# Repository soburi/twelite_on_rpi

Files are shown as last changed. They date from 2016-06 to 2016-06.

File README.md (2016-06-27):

TWE-Lite on RPi
===============

What is this?
-------------
TWE-LiteをRaspberry PiのUARTに直接接続するボードです。
ラズパイのケースにそのまま収まったり、TWE-LiteRのアダプタをケチれたりするので、
Border-Routerを作るときに役に立つはずのものです。

How to use it?
--------------
[私家版jenprog](https://github.com/soburi/jenprog)
[(https://github.com/soburi/jenprog)](https://github.com/soburi/jenprog)
で書き込みができるようになっています。

* TX     - RX
* RX     - TX
* GPIO9  - SPIMISO(Programming-mode)
* GPIO23 - reset

でTWE-LiteとRaspberryPiを接続しています。

```
jenprog -c serial -t /dev/ttyS0 --rpi --spimiso-pin=9 \
--reset-pin=23 --verbose -p slip-radio.jn516x.bin
```

のようにすると、イメージの焼き込みができます。
シリアルの指定はRPi3の場合は/dev/ttyS0、RPi2/1は/dev/ttyAMA0で。

SW1はリセットに繋がっています。所謂リセットボタン。

GPIO24はSW2に接続しています。明示的に機能は割り当てていないので、
RPi側のプログラムで任意に使用できます。
* GPIO24 - SW2

LED,SWはNXPのDR1174の接続に準拠しているので、
Contikiにある`JN516x_WITH_DR1174`の設定を使うときに便利です。
* DIO2 - LED1
* DIO3 - LED2
* DIO8 - SW3

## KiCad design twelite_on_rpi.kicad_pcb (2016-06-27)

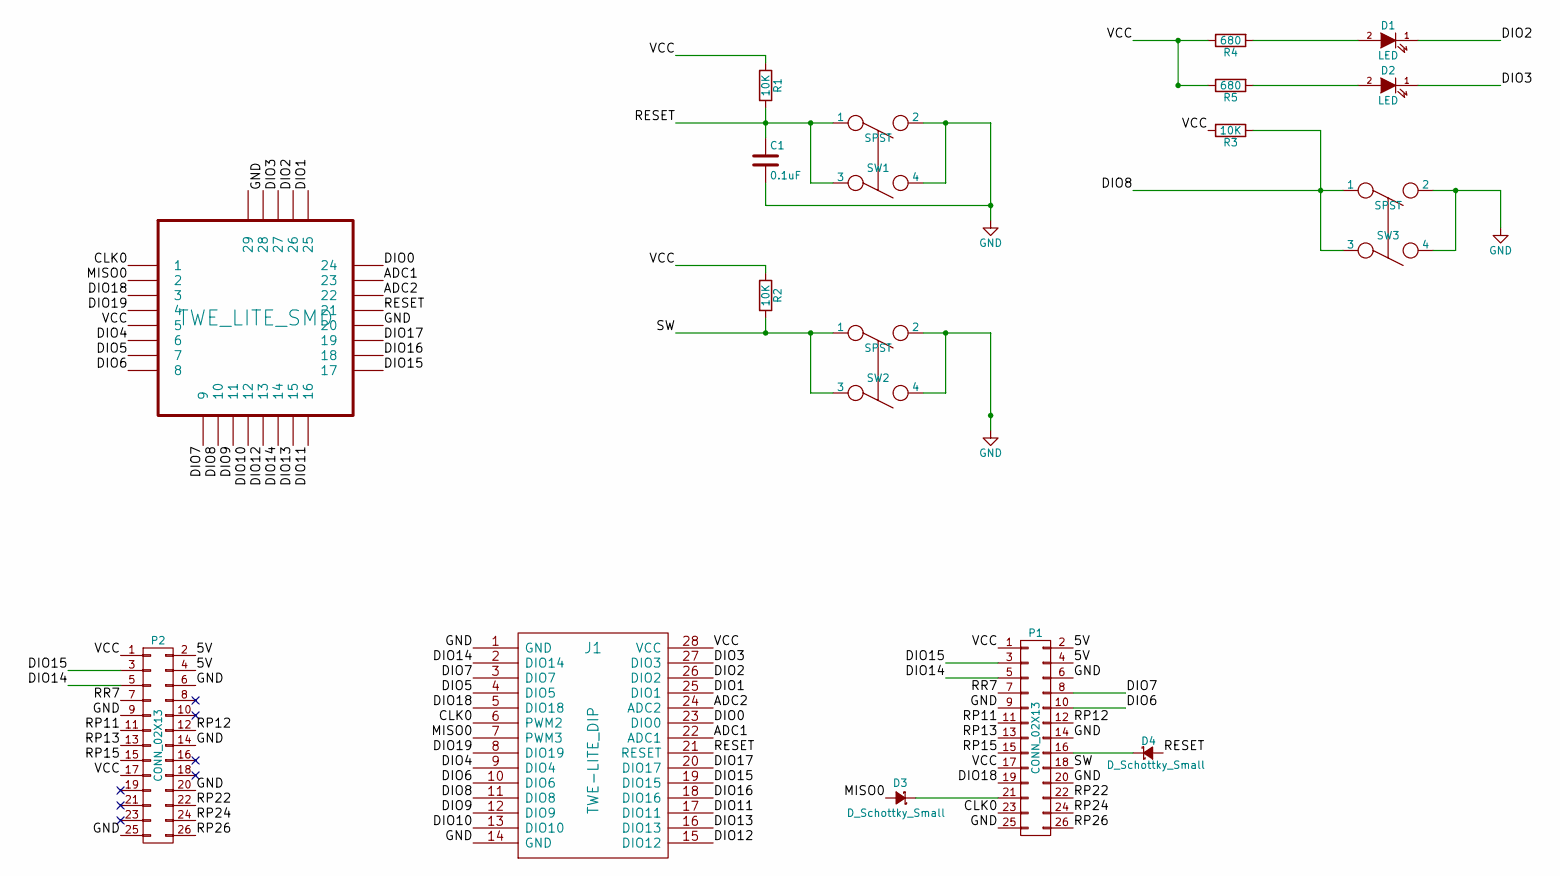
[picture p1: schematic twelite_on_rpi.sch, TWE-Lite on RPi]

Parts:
C1: 0.1uF; R_0603_HandSoldering
D1, D2: LED; LED-0805
D3, D4: D_Schottky_Small; R_0603_HandSoldering
J1: TWE-LITE_DIP; TWE-Lite_socket
P1, P2: CONN_02X13; Pin_Header_Straight_2x14
R1, R2, R3: 10K; R_0603_HandSoldering
R4, R5: 680; R_0603_HandSoldering
SW1, SW2, SW3: SPST; SKRPACE010
U1: TWE_LITE_SMD; TWE_LITE

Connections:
/5V: P1.2, P1.4, P2.2, P2.4
/ADC1: J1.22 (ADC1), U1.23
/ADC2: J1.24 (ADC2), U1.22
/CLK0: J1.6 (PWM2), P1.23, U1.1
/DIO0: J1.23 (DIO0), U1.24
/DIO1: J1.25 (DIO1), U1.25
/DIO2: D1.1 (K), J1.26 (DIO2), U1.26
/DIO3: D2.1 (K), J1.27 (DIO3), U1.27
/DIO4: J1.9 (DIO4), U1.6
/DIO5: J1.4 (DIO5), U1.7
/DIO6: J1.10 (DIO6), P1.10, U1.8
/DIO7: J1.3 (DIO7), P1.8, U1.9
/DIO8: J1.11 (DIO8), R3.1, SW3.1, SW3.3, U1.10
/DIO9: J1.12 (DIO9), U1.11
/DIO10: J1.13 (DIO10), U1.12
/DIO11: J1.17 (DIO11), U1.16
/DIO12: J1.15 (DIO12), U1.13
/DIO13: J1.16 (DIO13), U1.15
/DIO14: J1.2 (DIO14), P1.5, P2.5, U1.14
/DIO15: J1.19 (DIO15), P1.3, P2.3, U1.17
/DIO16: J1.18 (DIO16), U1.18
/DIO17: J1.20 (DIO17), U1.19
/DIO18: J1.5 (DIO18), P1.19, U1.3
/DIO19: J1.8 (DIO19), U1.4
/MISO0: D3.2 (A), J1.7 (PWM3), U1.2
/RESET: C1.1, D4.2 (A), J1.21 (RESET), R1.2, SW1.1, SW1.3, U1.21
/RP11: P1.11, P2.11
/RP12: P1.12, P2.12
/RP13: P1.13, P2.13
/RP15: P1.15, P2.15
/RP22: P1.22, P2.22
/RP24: P1.24, P2.24
/RP26: P1.26, P2.26
/RR7: P1.7, P2.7
/SW: P1.18, R2.2, SW2.1, SW2.3
/VCC: J1.28 (VCC), P1.1, P1.17, P2.1, P2.17, R1.1, R2.1, R3.2, R4.1, R5.1, U1.5
GND: C1.2, J1.1 (GND), J1.14 (GND), P1.6, P1.9, P1.14, P1.20, P1.25, P2.6, P2.9, P2.14, P2.20, P2.25, SW1.2, SW1.4, SW2.2, SW2.4, SW3.2, SW3.4, U1.20, U1.28
unnamed: D1.2 (A), R4.2
unnamed: D2.2 (A), R5.2
unnamed: D3.1 (K), P1.21
unnamed: D4.1 (K), P1.16

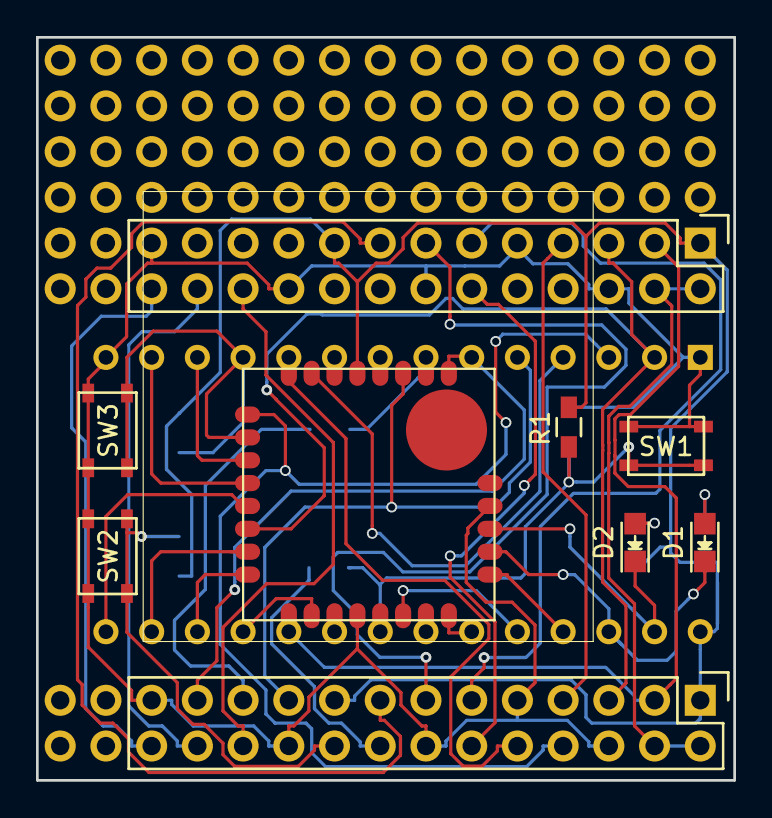
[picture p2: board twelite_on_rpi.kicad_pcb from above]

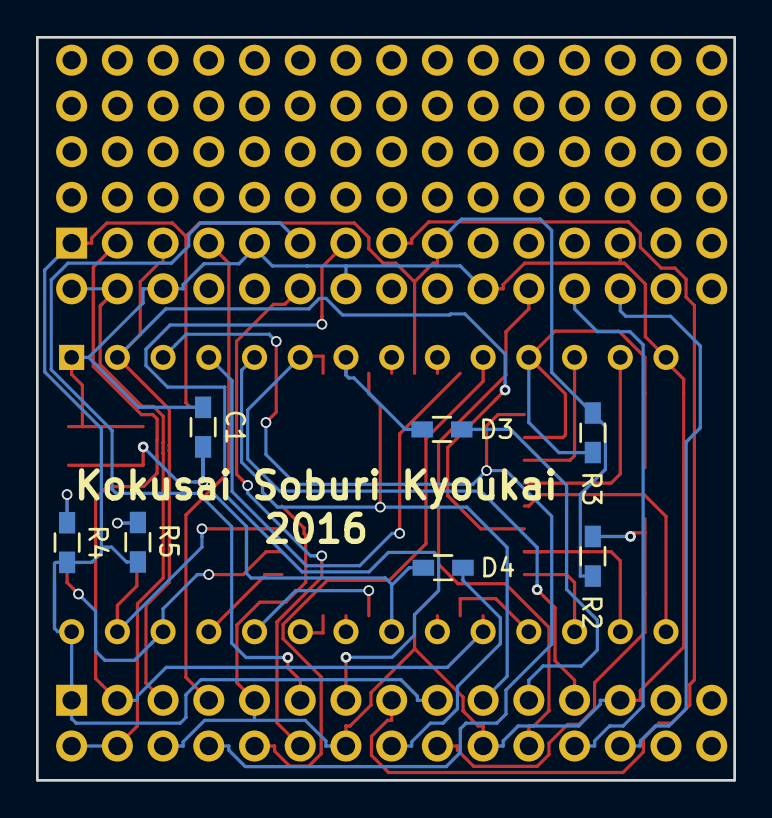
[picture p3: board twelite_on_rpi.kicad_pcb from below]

Board: 2 copper layers, 38.7 x 41.3 mm, 85 parts (7 on the bottom side), 41 nets.

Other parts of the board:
1, 2, 3, 4, 5, 6, 7, 8, 9, 10, 11, 12, 13, 14, 15, 16, 17, 18, 19, 20, 21, 22, 23, 24, 25, 26, 27, 28, 29, 30, 31, 32, 33, 34, 35, 36, 37, 38, 39, 40, 41, 42, 43, 44, 45, 46, 47, 48, 49, 50, 51, 52, 53, 54, 55, 56, 57, 58, 59, 60, 61, 62, 63, 64, 71, 72, 73, 74: SolderWirePad_single_Universal
